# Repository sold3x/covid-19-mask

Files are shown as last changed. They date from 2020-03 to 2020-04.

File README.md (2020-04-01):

# covid-19-mask
covid19 protection mask

In the course of the current Covid19 pandemic, we became aware of the face protection project by Josef Prusa https://www.prusa3d.com/covid19/. 

Together with doctors and nurses from everyday clinical practice, we have completely revised this face protection 
and optimized it in accordance with practical requirements. 

We would be happy to manufacture the mask for you. Please visit https://www.soldex.de for more informations.

If you have your own 3D printer, you are welcome to use our template free of charge.

The mask should be printed completely out of TPU with about 10% infill and a layerheight of youre choice. To get a compareable result, we are using 0.25.

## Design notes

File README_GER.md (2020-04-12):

# Soldex und Covid 19
Im Zuge der aktuellen Covid19 Pandemie wurden wir auf das Gesichtschutzprojekt von Josef Prusa aufmerksam. Gemeinsam mit Ärzten und Pflegern aus dem Klinikalltag haben wir diesen Gesichtsschutz vollständig überarbeitet und entsprechend der Anforderungen aus der Praxis optimiert. Gern fertigen wir das Visier für Sie. Falls Sie über einen eigenen 3D Drucker verfügen können Sie gern unsere Vorlage kostenfrei nutzen.

# Vergleich zu den Prusa Visieren
Was haben wir denn überhaupt alles verbessert? Die Punkte, die unsere Aufmerksamkeit bekamen, wurden uns von unseren Partnerkliniken nach und nach genannt, wodurch wir ein immer besser auf den Alltag zugeschnittenes Visier herstellen konnten.

## Desinfektion
Einer der genannten Nachteile war die schlechte Desinfizierbarkeit der Befestigungsgummis, sowie die Trennung von Shield und Träger. Bei häufigem Auseinanderbauen leierten die Löcher oft aus und das Visier musste entsorgt werden. Um dem Vorzubeugen besteht unser Visier aus 2 Teilen, die einfach auseinander und wieder zusammengebaut werden können, ohne ein Problem mit der Passung zu bekommen. 
Durch das komplett aus TPU gedruckte Band ist dieses auch strapazierbar, leiert quasi nicht aus und ist normal im Steriliumbad desinfizierbar. Für die Desinfektion kann das Visier also vollkommen demontiert und einzeln desinfiziert werden.

## Tragekomfort und Passgenauigkeit
Gerade die Notärzte aus den Rettungsstellen beklagten sich über einen schlechten Tragekomfort, sowie ein sehr dünnes Shield. Hierfür benutzen wir 1mm dickes PC, welches auch Stößen standhält, ohne sich dauerhaft zu verformen. Gerade bei solchen dicken war es schwer die Shields sicher an den Prusa Haltern zu befestigen, was gerade im Einsatz für uns ein nicht zu tragendes Risiko gewesen wäre. Unsere Masken sitzen fest und können auch leichten Schlägen standhalten. 
Der Tragekomfort definiert sich vor allem über den vorderen Teil des Trägers, der bei uns aus TPU anstelle von PETG besteht und damit Stabilität, aber auch flexible Anpassung an die Kopfform gewährleistet. Durch unsere verbundenen Gummibänder lassen sich verschiedene Einstellungen wählen, die auf verschiedenste Kopfgrößen angepasst werden können.

## Druckzeit
Unsere Masken drucken in den genannten Einstellungen ungefähr 4,5-5h, was in etwa dem Prusa Visier mitsamt einem TPU Gummiband entspricht. Mit größerer Nozzle sind Druckzeiten auch unter 2 Stunden möglich.

## Einstellmöglichkeiten
Neben dem verstellbaren Band lässt sich auch das Shield ab Version 5 in verschiedene Rastpositionen bringen. Damit kann der Kopf gerade bei kleineren Personen deutlich freier bewegt werden und bietet gleichzeitig oben weiteren Schutz.

## Shield
Wie bereits genannt ist unser Shield deutlich dicker und robuster als die meisten verwendeten Laminierfolien, was sie nachhaltiger und beständiger macht. So kann gerade in Kliniken das Visier einfach auseinandergebaut, desinfiziert und theoretisch an die nächste Schicht übergeben werden, ohne ein defektes Shield zu riskieren. 
Außerdem ist es etwas größer und schützt gerade oberhalb des Kopfes weitere Teile des Gesichts.

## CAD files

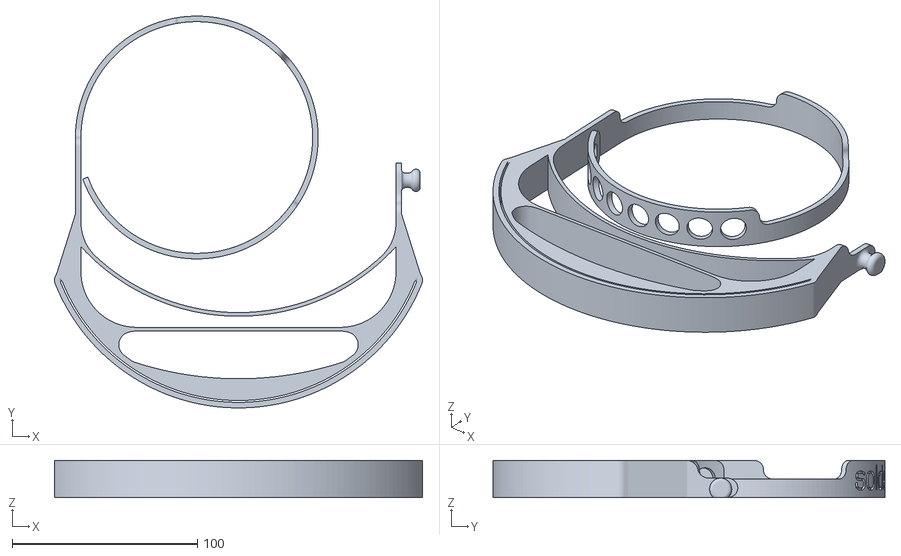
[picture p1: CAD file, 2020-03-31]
Holder/Soldex_Maske V4.stl
198.6 x 211.4 x 20.0

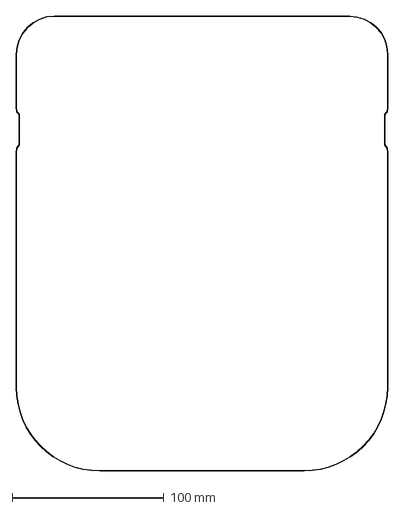
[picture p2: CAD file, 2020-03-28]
Shield/Soldex_Shield V4.dxf
245.0 x 300.0 mm

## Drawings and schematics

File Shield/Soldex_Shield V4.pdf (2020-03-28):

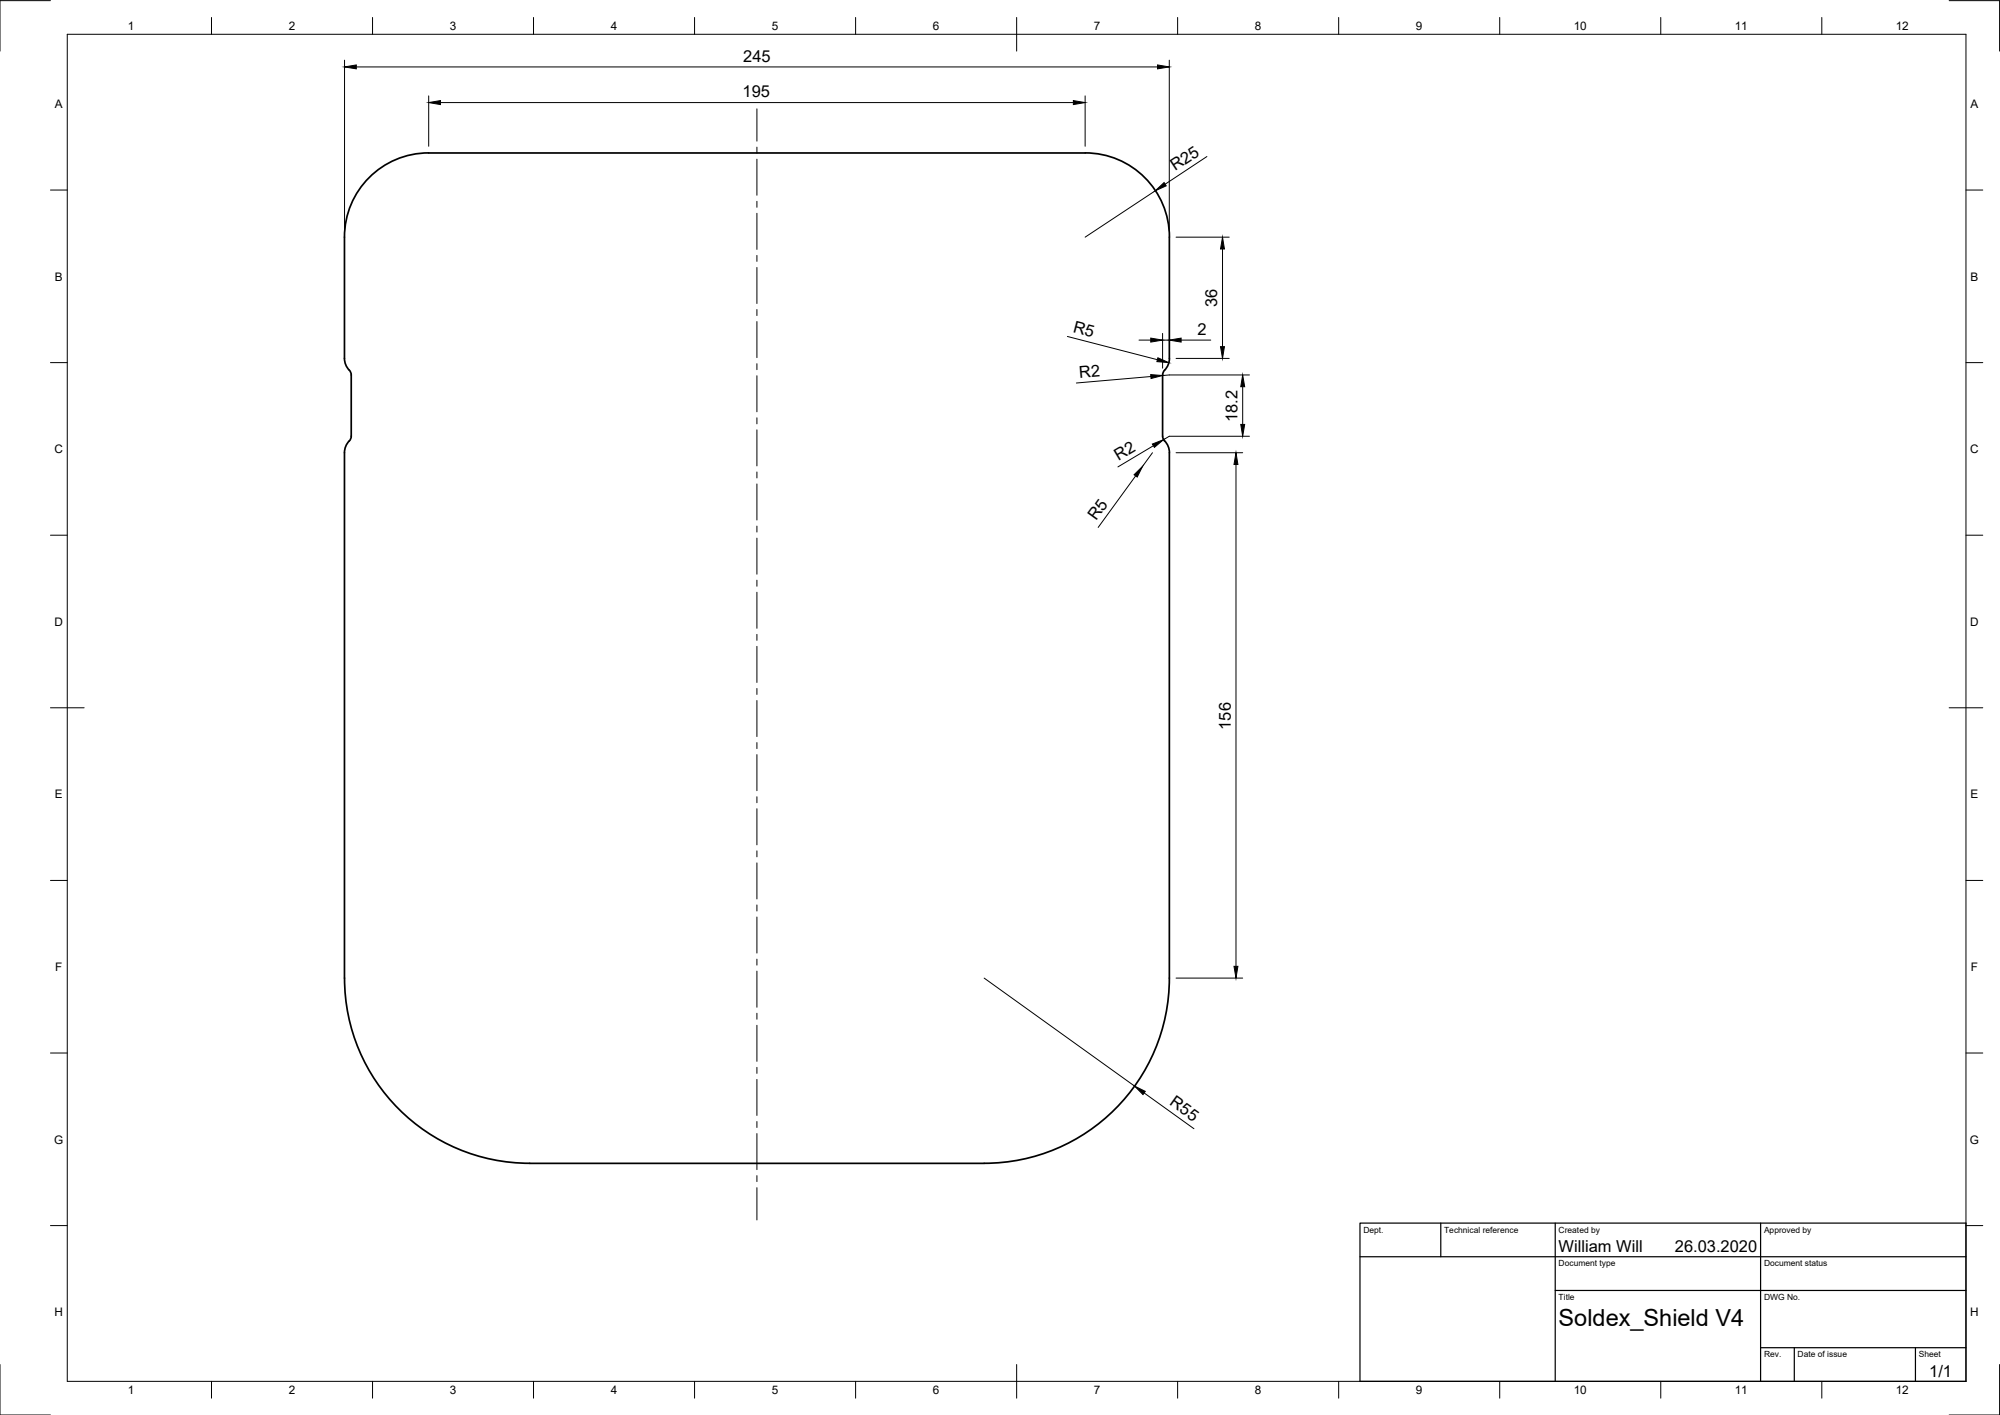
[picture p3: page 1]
William Will 156

Dept. | Technical reference | Created by 26.03.2020 | Approved by

Document type | Document status

Title Soldex_Shield V4 | DWG No.

Rev. | Date of issue | Sheet 1/1

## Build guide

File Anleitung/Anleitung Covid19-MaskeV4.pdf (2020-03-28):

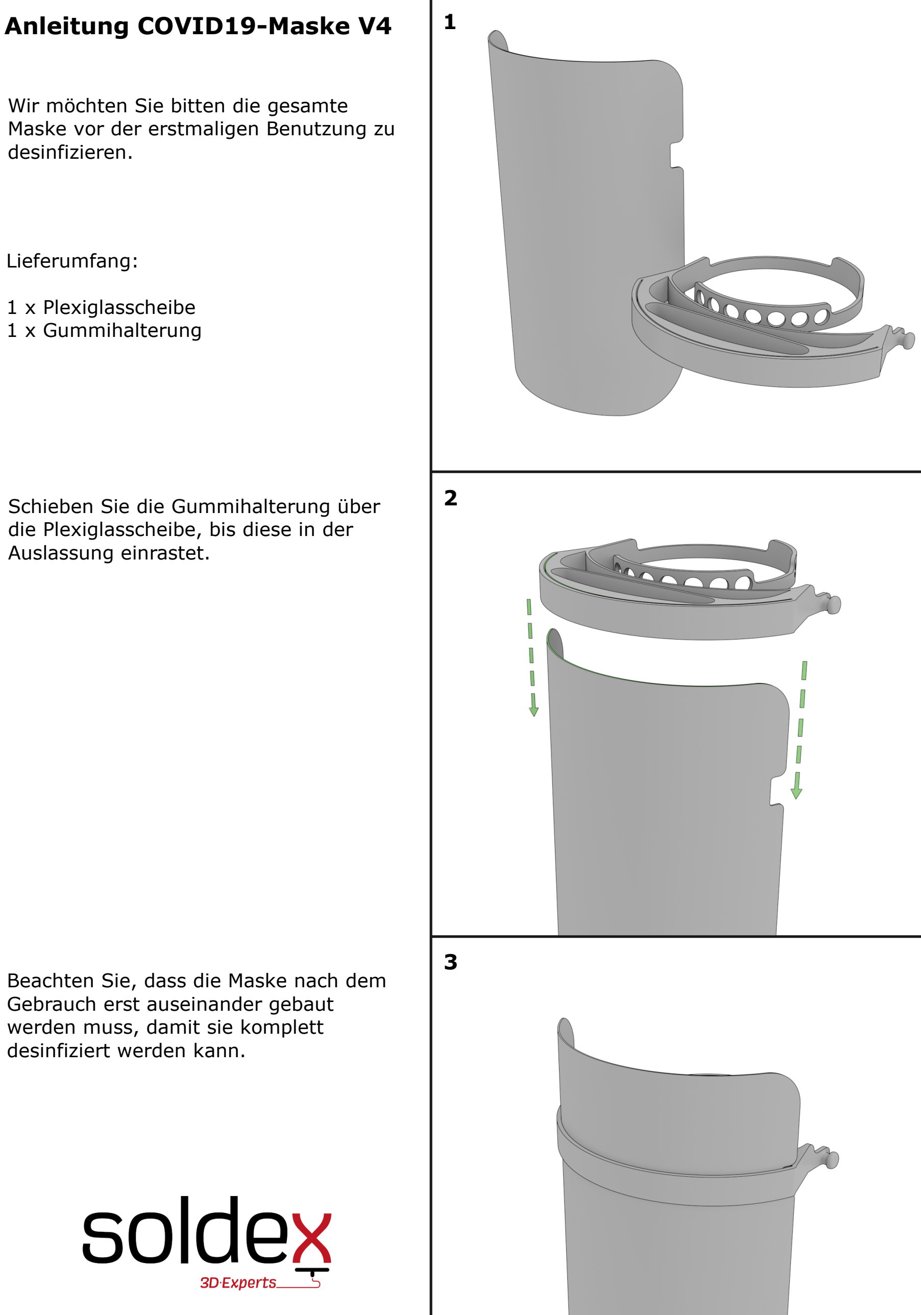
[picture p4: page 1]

### Anleitung COVID19-Maske V4

Beachten Sie, dass die Maske nach dem Gebrauch erst auseinander gebaut werden muss, damit sie komplett desinfiziert werden kann.

Wir möchten Sie bitten die gesamte Maske vor der erstmaligen Benutzung zu desinfizieren.

Lieferumfang:

1 x Plexiglasscheibe
1 x Gummihalterung

Schieben Sie die Gummihalterung über die Plexiglasscheibe, bis diese in der Auslassung einrastet.

3

2

1

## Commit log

2020-03-28 first files from version 4
    [Soldex_Maske V4.stl, Soldex_Shield V4.dxf]
2020-03-31 better Version 5 File
    [Soldex_Maske V4.stl]
